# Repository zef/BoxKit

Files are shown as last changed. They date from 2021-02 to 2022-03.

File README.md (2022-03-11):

# BoxKit

An open-source library of 3d printable parts for making low-cost boxes, trays,
and bins. You can also view pictures and download the source from [the BoxKit page on Prusa Printers](https://www.prusaprinters.org/prints/57813-boxkit-parts-for-making-custom-boxes-trays-and-bin).

3d printing can be a great way to make small bins and boxes, but it's not
always possible or economical for larger items.

BoxKit enables the easy creation of these types of bins using thin sheet goods
such as acrylic, plywood, or MDF panels, with small, cheap, 3d printed parts
for the corners. The corners can be secured in place with CA glue.

This is a quick, cheap, and efficient way of creating all sorts of small parts
bins. The parts are designed to print with no supports.

I would like to make a video explaining and demonstrating some of the features
and process. Coming soon, I hope!

### Flexible, Modular, and Customizable

Quickly print a set of corners that will allow you to assemble a box of any
size.

Choose a simple tray or a box with a hinged lid. Optional features include
lid latches, magnets, independent hinges, and other configurable options, [as
detailed below](#boxkit-parts).

Parameters such as the thickness of the material, side length, height, hinge
configuration, and many other configuration options are available.

Modify the parameters using the [OpenSCAD](https://www.openscad.org) program.

No coding is required for changing parameters due to the Customizer, which
allows configuration through a friendly interface.

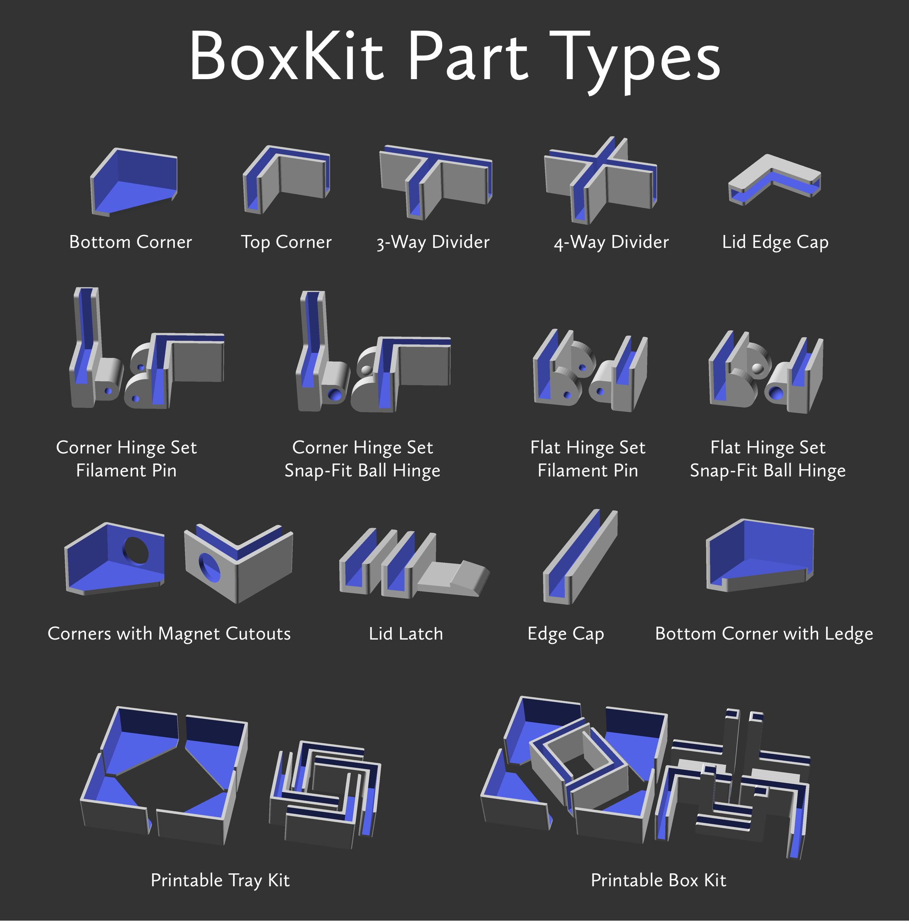
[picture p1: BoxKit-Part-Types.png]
BoxKit Part Types


## Process

Steps to create a box include:

- sourcing materials
- configuring and printing parts
- cutting panels to size
- assembling

### Sourcing Materials

For me, a large part of the motivation for this project is that I had a lot of
the freely-acquired clear acrylic that was bound for the trash before I got it.

I can frequently find acrylic sheet scraps for free from a local plastics
supplier that throws out smaller offcuts in a bin next to their dumpster. You
can probably find something like this too!

I also think it could be a good use of smaller scrap offcuts of thin sheet goods
like MDF or plywood that you may have lying around the shop, or are able to
reclaim for free from somewhere.

I can often find such materials very cheaply at a local used building materials
yard, such as a [Habitat ReStore](https://www.habitat.org/restores), or similar.

I encourage you to use reclaimed materials where possible! Reducing waste and
making something useful out of "trash" is important, and has value that goes
beyond a simple monetary calculation, though it can also be very economical.

### 3d Part Configuration

All dimensions are in mm.

Two of the most important parameters are:
- `stock thickness`, which represents the thickness of the material that you are using
- `perimeters`, which is used — along with `extrusion width` — to determine the
  thickness of the plastic walls that make up the structure of plastic part.

The wall thickness of the plastic is determined by the number of perimeters set
in the configuration, multiplied by the extrusion width. I have been pleasantly
surprised by the strength and suitability of using only two perimeters, but I
have experimented with both two (2p) and three (3p) perimeter configurations. 3p
is good for larger boxes and trays, but 2p is quite good too and uses only about
60% of the plastic that 3p does.

In my testing on a 3mm panel, a clearance of -.1 works well with 2p panels,
while a clearance of .1 works well with 3p panels.

In OpenSCAD, you can choose from many options in the "print parts" selection.
Each option displays certain parts that are generally appropriate to print
together. However, you can use features of your slicer, such as "Split to parts"
or "Split to objects", as in Prusa Slicer, to easily isolate a certain part and
print just that, if desired.

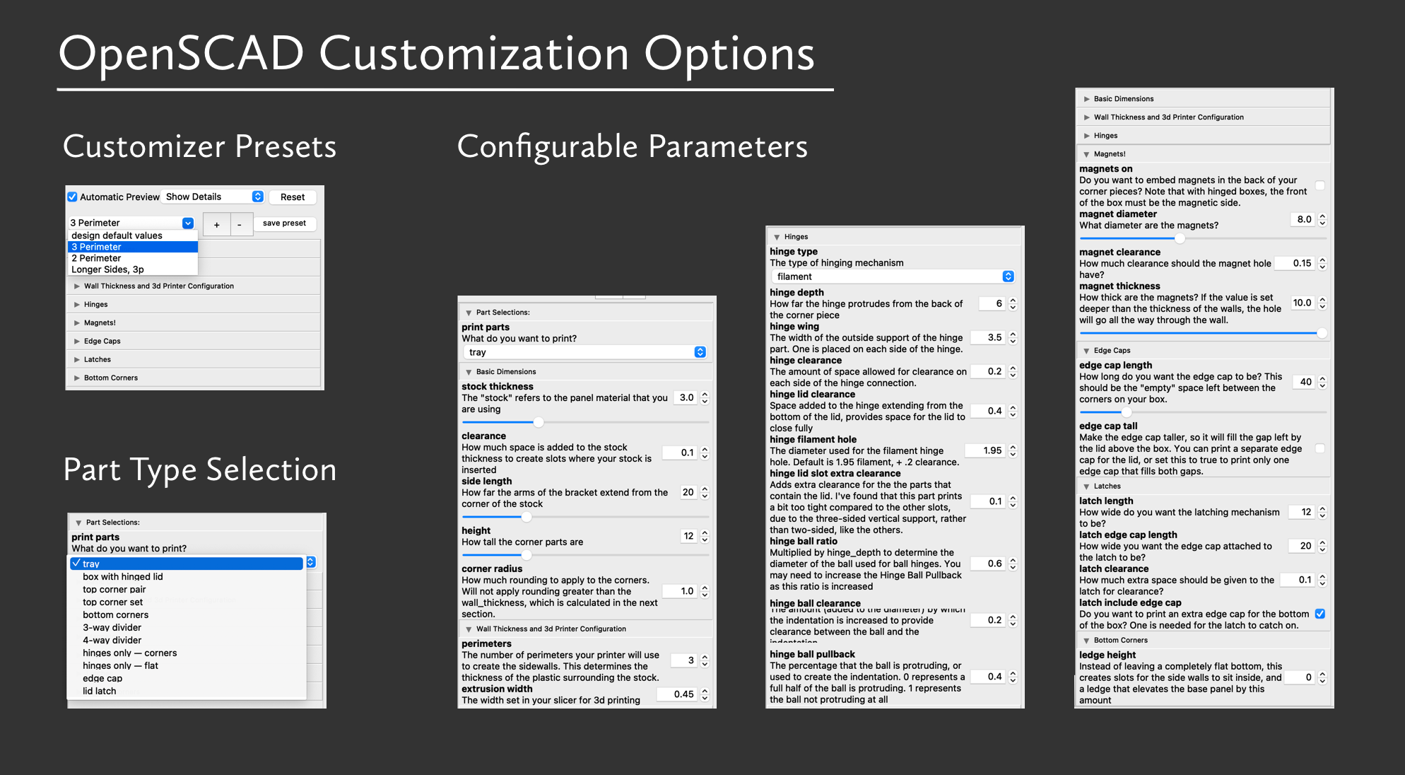
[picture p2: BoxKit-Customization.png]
BoxKit Configuration Options


#### Printing Notes

My parts are printed with PETG:
- white is [MatterHackers Build series](https://www.matterhackers.com/store/l/petg-white-high-strength-filament-1.75mm/sk/M1VF5877)
- black is [Prusament Galaxy Black](https://shop.prusa3d.com/en/prusament/1006-prusament-petg-prusa-galaxy-black-1kg.html)

With PETG, I have personally found it essential to slow down the first-layer
speed to get good adhesion and a clean first layer. I could not get consistent
results using the default Prusa Slicer profiles. I am using a 10mm/s First layer
speed, and that is working well for me.

### Cutting Panels

When making a box or tray, I like to have the bottom of the box completely inset
inside the walls of the box. I will expand on this process later, but for now,
it is an exercise for the reader. Stay safe — don't make any cuts that you're not
comfortable with. I'm sure you'll figure it out. ;)

### Assembly

I like to get everything lined up and test fit before starting the gluing
process, then go around and glue a corner at a time, top corners first. Then
inserting the bottom panel and gluing on the bottom corners after the top is set
up. Some gentle clamping may help too, depending on the size of everything.

Since the bottom corners are just flat in the base configuration, it can be a
little tricky to keep them on properly. See the "ledge height" option in the
"Bottom Corners" customizer section for another option that holds the sidewalls
better.

For gluing, I have used both [medium](https://amzn.to/3J4RF8L) or
[thick](https://amzn.to/3pZprVb) 2P-10 CA glue and they both work well. Medium
can be quite runny and you have to be careful to not let it drip, but it's
slightly easier for me to work with than the thick. I try to apply a small
amount to the cavity of the part and then press in the panel. Thick tends to
have more squeeze-out and it's harder for me to control the application amount.

Watch out, as some plastics can be discolored by CA glue activators.

### How to use the OpenSCAD file

The OpenSCAD Customizer can be used to drive most changes that I expect you will
need. Let me know if there is anything missing!

Basic steps to get started are as follows:

- Install the [OpenSCAD](https://www.openscad.org) program.
- Install the libraries as detailed in the following links: [Round Anything](https://github.com/Irev-Dev/Round-Anything/discussions/21)
and [BOSL](https://github.com/revarbat/BOSL/wiki).
- Download the code for this project from GitHub — see the link on the top right
  of the project page.
- Open BoxKit.scad, and start exploring the Customizer options. Don't be afraid
  to edit the values in the code, too!
- Once you have something you want to try, you must first Render the part, and
  then Export as STL. Both of these are in the application menus, and available
  as icons in the interface.

Note: the OpenSCAD Customizer does not allow subdivisions of numbers that
started out as integers, for instance, if a value started out as "3",
the Customizer does not allow you to input 3.1. You can deal with this by
editing the code, though I've tried to work around the issue for some cases.

---

# BoxKit Parts

## Basic Box Types

### Tray

Four bottom corners and four top corners that are assembled to create a simple
tray or lidless box.

### Box

Just like a tray, but with a hinged lid. Two of the top corners are replaced
with hinge parts.  Additionally, two hinges are added for back of the lid, and
two covers for the front of the lid.

## Options and Accessories

### Hinges

The hinges are designed to open to a nice stop point, so the lid opens to about
30º past 90º.

The hinge type can be configured as:

#### Filament:

A pinned hinge, using a piece of filament as the pin. This is a very simple way
to create a nicely operating hinge that is less finicky than the "ball" hinge.
This is my preference.

#### Ball:

A snap-fit half-ball indentation that provides a convenient way to attach two
hinge pieces. I have had some success with the ball hinge, but I find it to be
more sensitive to small configuration changes. It can be hard to assemble if
the tolerances are too tight, and can damage the hinge slightly during assembly.
However, if tolerances are too loose, the hinge does not provide much friction
and becomes floppy. Due to this, I personally prefer the filament hinge. Also,
the ball hinge requires more rendering time in OpenSCAD.

### Edge Cap

In this simple design, there is a gap between the top of the box sides and the
bottom of the lid. This is suitable for many purposes. However, if a
more-refined and fully-enclosed box is desired, you can use an `edge_cap` piece
to fully cover the top edges of the box.

There is also an `edge cap tall` option that is explained in the Customizer.

### Lid Latch

A Lid Latch can be added to create a securely closing lid. Due to the printing
orientation, the layers of the lid can catch when closing, so this part should
be printed with finer layer height settings than other parts, like .1mm.

Some light filing/sanding also helps to get the latch to close smoothly. I am
open to other design ideas that could improve this situation, I have a couple
ideas but haven't had time to implement and test them yet.

The latch is an add-on to the edge cap part, so it can be printed on top of an
edge cap of variable width, allowing you to create a more enclosed box.

### Dividers

Dividers can be added by printing the three-way and four-way corner parts.

### Flat Hinges

Boxes are easily created by building a hinge into the top corner piece, but a
"flat" hinge piece is also available to retrofit lids to existing trays.

### Magnets!

Magnets can be embedded in the rear parts of a box. In a brief test using four
8mm diameter, 1mm thick magnets [such as these](https://amzn.to/34ANB0N), a
small box was able to hold some small items and remain stuck to the side of my
fridge, but it was not particularly strong with such small magnets. Perhaps
doubling the magnets or using a larger magnet would work well. Note that you may
need to increase the wall-thickness by increasing the number of perimeters if
you want your magnet to be fully-embedded.

---

## Open-Source

Modify and contribute improvements, new ideas, and new features!

#### Feature ideas:

- **Stackability**

  I would be interested in a good implementation of stackable boxes of the same
  size. I haven't found a great way to implement this in an elegant, printable
  way. One idea would be to have a separately-printed disc or triangle that
  glues into a cavity that is printed into the bottom of the bottom-corner part.
  But I don't find extra assembly steps to be very elegant or worthwhile. I
  experimented with an "interlock" feature that is in the code behind a feature
  flag, but I have not tried to print it and am skeptical of it anyway.

- **Shelf Slot**

  Okay, so it's not _exactly_ box related, but this would be pretty easy and
  might be a nice way to mount panels as shelves. I have this partially
  implemented (`back_plate()`), just haven't been able to finish and test it yet.

- **Automate Exports**

  I'd love to be able to change some parameters and run a command-line script
  that would export all the part types, named by convention. [This should be
  doable.][1]

[1]: https://en.wikibooks.org/wiki/OpenSCAD_User_Manual/Using_OpenSCAD_in_a_command_line_environment

### Known Issues

- some part layouts do not behave properly when exaggerated dimensions are used.
  I think in normal usage this shuold be ok, but let me know otherwise.

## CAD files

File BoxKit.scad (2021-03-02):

// https://github.com/zef/BoxKit


// Using some dependencies helps keep me sane. Please excuse the inconvenience of installation :)


// https://github.com/Irev-Dev/Round-Anything
//
// Installation instructions: https://github.com/Irev-Dev/Round-Anything/discussions/21
include <Round-Anything/polyround.scad>

// https://github.com/revarbat/BOSL/wiki
//
// Installation instructions: https://github.com/revarbat/BOSL/wiki
include <BOSL/constants.scad>
use <BOSL/transforms.scad>
use <BOSL/shapes.scad>


/* [Part Selections:] */

// What do you want to print?
print_parts = "tray"; //[tray, box with hinged lid, top corner pair, top corner set, bottom corners, 3-way divider, 4-way divider, hinges only — corners, hinges only — flat, edge cap, lid latch]


/* [Basic Dimensions] */
// The "stock" refers to the panel material that you are using
stock_thickness = 3; // [0:.1:10]

// the .01 here is used to allow granularity in the Customizer.

// How much space is added to the stock thickness to create slots where your stock is inserted
clearance = 0.1;

// How far the arms of the bracket extend from the corner of the stock
side_length = 20; // [10:1:50]

// How tall the corner parts are
height = 12; // [6:1:30]

// How much rounding to apply to the corners. Will not apply rounding greater than the wall_thickness, which is calculated in the next section.
corner_radius = 0.8;

/* [Wall Thickness and 3d Printer Configuration] */

// The number of perimeters your printer will use to create the sidewalls. This determines the thickness of the plastic surrounding the stock.
perimeters = 3;

// The width set in your slicer for 3d printing
extrusion_width = 0.45;


// The wall thickness determines:
// - the thickness of vertical walls that surround the stock
// - the thickness of the
wall_thickness = perimeters * extrusion_width;
slot_thickness = stock_thickness + clearance;
total_wall = (wall_thickness * 2) + slot_thickness;


/* [Hinges] */

// The type of hinging mechanism
hinge_type = "filament"; // [none, filament, ball]

// How far the hinge protrudes from the back of the corner piece
hinge_depth = 6;

// The width of the outside support of the hinge part. One is placed on each side of the hinge.
hinge_wing = 3.5;


// The amount of space allowed for clearance on each side of the hinge connection.
hinge_clearance = 0.2 ;

// Space added to the hinge extending from the bottom of the lid, provides space for the lid to close fully
hinge_lid_clearance = 0.4;


// The diameter used for the filament hinge hole. Default is 1.95 filament, + .2 clearance.
hinge_filament_hole = 1.95;


// Adds extra clearance for the the parts that contain the lid. I've found that this part prints a bit too tight compared to the other slots, due to the three-sided vertical support, rather than two-sided, like the others.
hinge_lid_slot_extra_clearance = .1;


hinge_inside_length = side_length - (hinge_wing + hinge_clearance) * 2;

// Multiplied by hinge_depth to determine the diameter of the ball used for ball hinges. You may need to increase the Hinge Ball Pullback as this ratio is increased
hinge_ball_ratio = 0.6;

// The size of the ball that is used for ball hinges
hinge_ball = hinge_depth * hinge_ball_ratio;

// The amount (added to the diameter) by which the indentation is increased to provide clearance between the ball and the indentation
hinge_ball_clearance = .2;

// The percentage that the ball is protruding, or used to create the indentation. 0 represents a full half of the ball is protruding. 1 represents the ball not protruding at all
hinge_ball_pullback = .4;



/* [Magnets!] */

// Do you want to embed magnets in the back of your corner pieces? Note that with hinged boxes, the front of the box must be the magnetic side.
magnets_on = false;

// What diameter are the magnets?
magnet_diameter = 8; // [0:.1:20]

// How much clearance should the magnet hole have?
magnet_clearance = 0.15;

// How thick are the magnets? If the value is set deeper than the thickness of the walls, the hole will go all the way through the wall.
magnet_thickness = 10; // [0:.1:10]


/* [Edge Caps] */

// How long do you want the edge cap to be? This should be the "empty" space left between the corners on your box.
edge_cap_length = 40; // [6:1:200]

// Make the edge cap taller, so it will fill the gap left by the lid above the box. You can print a separate edge cap for the lid, or set this to true to print only one edge cap that fills both gaps.
edge_cap_tall = false;

/* [Latches] */

// How wide do you want the latching mechanism to be?
latch_length = 12;

// How wide you want the edge cap attached to the latch to be?
latch_edge_cap_length = 20;

// How much extra space should be given to the latch for clearance?
latch_clearance = 0.1;

// Do you want to print an extra edge cap for the bottom of the box? One is needed for the latch to catch on.
latch_include_edge_cap = true;


/* [Bottom Corners] */

// Instead of leaving a completely flat bottom, this creates slots for the side walls to sit inside, and a ledge that elevates the base panel by this amount
ledge_height = 0;



radius = min(corner_radius, wall_thickness);


echo("<b>Wall: ", wall_thickness);
echo("<b>Total Wall: ", total_wall);
echo("<b>Calculated Corner Radius: ", radius);

// could do some parameter validation, but may be fine to leave that to the user


module slot() {
  translate([wall_thickness, wall_thickness, wall_thickness])
    cube([slot_thickness, side_length, height]);
}


// hiding this down here so it's not in the customizer
$fn = 60;

module bottom_corner_triangle_shape() {
  polygon(
      polyRound([
        [0,0, radius],
        [0, side_length, radius],
        [total_wall, side_length, radius],
        [side_length, total_wall, radius],
        [side_length, 0, radius]
      ])
    );
}

module corner_shape() {
  polygon(
      polyRound([
        [0,0, radius],
        [0, side_length, radius],
        [total_wall, side_length, radius],
        [total_wall, total_wall, radius],
        [side_length, total_wall, radius],
        [side_length, 0, radius]
      ])
    );
}

module magnet() {
  if (magnets_on) {
    // get rid of OpenSCAD artifact
    pull = .2;
    magnet_diameter = magnet_diameter + magnet_clearance;

    magnet_thickness = min(magnet_thickness, wall_thickness) + pull;
    move(x=magnet_thickness/2 - pull/2, y=side_length/2, z=height/2)
      xcyl(l=magnet_thickness, d=magnet_diameter);
  }
}

module bottom_corner(interlock=false, magnets=false) {
  difference() {
    linear_extrude(height) {
      bottom_corner_triangle_shape();
    }

    // cutout slots for panels
    slot();
    zrot(270) left(total_wall) slot();

    // flatten out inside ledge, providing suppport for the bottom part
    translate([slot_thickness, slot_thickness, wall_thickness + ledge_height]) cube([side_length, side_length, height]);

    if (magnets) {
      magnet();
    }

    if (interlock) {
      interlock();
    }
  }
}


module top_corner(interlock=false, magnets=false) {
  union() {
    difference() {
      linear_extrude(height) {
        corner_shape();
      }

      slot();
      zrot(270) left(total_wall) slot();

      if (magnets) {
        magnet();
      }
    };

    if (interlock) {
      interlock();
    }
  }
}

module 3_way() {
  difference() {
    mirror_copy([0,1,0], 0, [0,(wall_thickness + slot_thickness/2),0]) top_corner();
    forward(side_length / 2) slot();
  }
}

module 4_way() {
  difference() {
    mirror_copy([1,0,0], 0, [(wall_thickness + slot_thickness/2),0,0]) 3_way();
    zrot(90) forward((wall_thickness*3) + side_length/2) slot();
  }
}


// an idea for a shelf holder plate
//module back_plate(side=10) {
//    plate_height = side * .6;
//
//    mirror_copy([0,0,1], 0, [0,0,total_wall/2])
//    difference() {
//        yrot(90) xflip() left(plate_height)
//        linear_extrude(side) polygon(
//            polyRound([
//                [0,0, 0],
//                [0, wall_thickness, 2],
//                [plate_height, wall_thickness, 4],
//                [plate_height, wall_thickness * 4, 0],
//                [plate_height + total_wall, wall_thickness * 4, 0],
//                [plate_height + total_wall, 0, 0],
//            ])
//        );
//
//        xrot(90, cp = [0,0,wall_thickness/2])  right(side/2) forward(plate_height/1.7)  cylinder(wall_thickness+.1, 4, 2);
//    }
//}

module lid_corner() {
  difference() {
    linear_extrude(total_wall + hinge_lid_slot_extra_clearance) {
      corner_shape();
    }

    // cut out slot for shelf sheet
    cut_depth = wall_thickness;
    translate([cut_depth, cut_depth, wall_thickness]) cube([side_length, side_length, slot_thickness + hinge_lid_slot_extra_clearance]);
  };
}
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

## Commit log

2021-01-18 Commit initial implementation with 4 basic models.
    [BoxKit.scad]
2021-01-18 Refactor to use some BOSL helpers.
    [BoxKit.scad]
2021-02-01 Extract some of the shape logic to modules. Implement idea for "interlocking" parts that can be stacked.
    Try out wall mount idea for a shelf, haven't tried it.
    [BoxKit.scad]
2021-02-03 Add some documentation about variable names, improve formatting.
    [BoxKit.scad]
2021-02-03 Add some nice layout methods for generating all the parts needed for a box
    [BoxKit.scad]
2021-02-03 Some hinge experiments, though these are partial and will change.
    [BoxKit.scad]
2021-02-03 Implement more elegant tiling.
    [BoxKit.scad]
2021-02-03 Disable unused back_plate code for now.
    [BoxKit.scad]
2021-02-03 Work on hinge types.
    [BoxKit.scad]
2021-02-04 Work on hinge types, refine ball hinge especially.
    [BoxKit.scad]
2021-02-04 camelCase -> snake_case, other formatting consistency improvements.
    [BoxKit.scad]
2021-02-04 Improve presentation of hinges, create layout for printing hinges.
    [BoxKit.scad]
2021-02-04 sideLength -> side_length
    [BoxKit.scad]
2021-02-04 Add a small amount of protection against bad parameters in the box hinge corner.
    [BoxKit.scad]
2021-02-04 Flip corner hinge so that printing a test pair prints a matching pair of hinges.
    [BoxKit.scad]
2021-02-04 Fix hinge bug where the round wasn't fully removed.
    [BoxKit.scad]
2021-02-04 Organize and document variables a bit.
    [BoxKit.scad]
2021-02-04 Fix ball hinge accuracy problem. Improve clearances, add some new variables.
    [BoxKit.scad]
2021-02-07 Start work on flat slot hinge part.
    [BoxKit.scad]
2021-02-16 Clean up connection for flat hinges. Clean up logic for projection. Rename some modules.
    [BoxKit.scad]
2021-02-16 Get rid of separate outside corner round.
    [BoxKit.scad]
2021-02-17 Better formatting of parameter documentation.
    [BoxKit.scad]
2021-02-17 Implement parameter that enables part selection to show what parts should be printed.
    Some nice refactoring and other improvements too.
    [BoxKit.scad]
2021-02-17 Fix bug where hinge_depth was not used properly to fill gap.
    [BoxKit.scad]
2021-02-17 Add front lid corners to hinge set.
    [BoxKit.scad]
2021-02-18 Implement support for embedded magnets on back of box.
    [BoxKit.scad]
2021-02-19 A couple documentation improvements.
    [BoxKit.scad]
2021-02-20 Implement lid latch.
    [BoxKit.scad]
2021-02-20 Improve docs and defaults a bit.
    [BoxKit.scad]
2021-02-20 Implement tighter spacing when printing a hinged box.
    [BoxKit.scad]
2021-02-20 Some general code cleanup
    [BoxKit.scad]
2021-02-20 Minor latch design adjustments.
    [BoxKit.scad]
2021-02-20 Rearrange variables, improve comments.
    [BoxKit.scad]
2021-02-20 Limit the applied radius to the wall_thickness. Prevents some bad behavior if greater.
    [BoxKit.scad]
2021-02-20 In corner hinge set, flip the lid corners for printing, as before.
    [BoxKit.scad]
2021-02-20 Update some configuration defaults.
    [BoxKit.scad]
2021-02-21 Rename some options and improve code comments.
    [BoxKit.scad]
2021-02-21 Add some ranges to parameters for the Customizer.
    [BoxKit.scad]
2021-02-21 A bit of documentation formatting.
    [BoxKit.scad]
2021-02-21 Code formatting changes.
    [BoxKit.scad]
2021-02-22 Add printing notes to README, and a few other minor changes.
2021-03-02 Add dependency installation links.
    [BoxKit.scad]
2022-03-11 Update with link to Pruas Printers page, update Amazon links.
